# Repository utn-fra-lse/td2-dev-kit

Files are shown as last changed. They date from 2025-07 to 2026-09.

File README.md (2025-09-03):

# td2-dev-kit

El objetivo de este kit de desarrollo es proveer un hardware común para las plataformas de la cátedra de Técnicas Digitales II, siendo estas el ESP32 y la Raspberry Pi Pico 2.

## Pinouts de placas de desarrollo

Abajo están los pinouts de las placas de desarrollo que usamos en la cátedra

### ESP32 Devkit C1

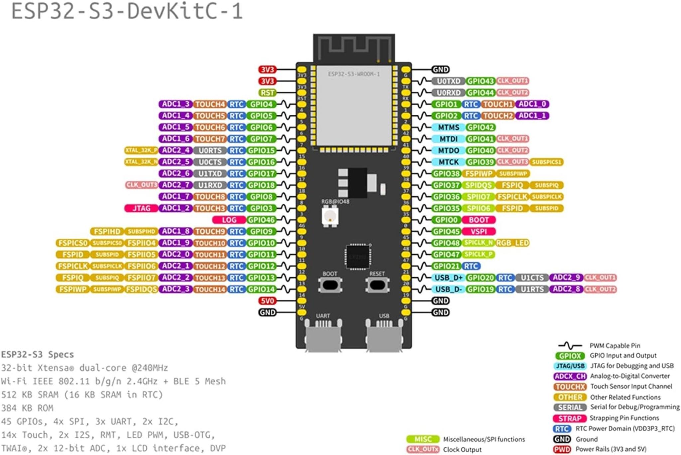
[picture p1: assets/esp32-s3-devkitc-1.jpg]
ESP32 S3 Devkit C1


### Raspberry Pi Pico 2W

Raspberry Pi Pico 2W

## Kit de desarrollo

Este va a ser nuestro kit de desarrollo para toda la cátedra.

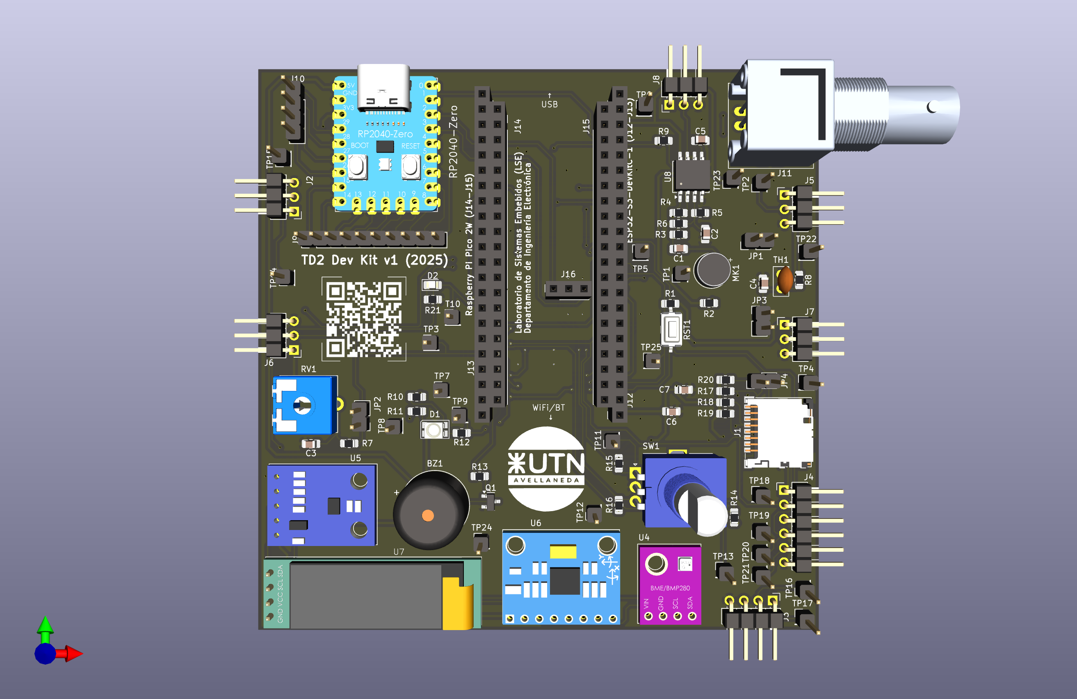
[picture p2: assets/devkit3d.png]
Dev kit


Tiene una variedad de periféricos para poder usar que a continuación vamos a mencionar brevemente.

### Entradas y salidas digitales

| GPIO RPico 2W | GPIO ESP32 | Dispositivo |
| --- | --- | --- |
| 2 | 9 | Output A de encoder rotativo |
| 3 | 10 | Output B de encoder rotativo |
| 12 | 37 | Botón de encoder rotativo |
| 11 | 8 | Buzzer pasivo |
| 10 | 38 | Ánodo LED individual |
| 15 | 5 | Cátodo LED rojo (RGB) |
| 13 | 6 | Cátodo LED verde (RGB) |
| 14 | 7 | Cátodo LED azul (RGB) | 

### Entradas analógicas

| GPIO RPico 2W | GPIO ESP32 | Dispositivo |
| --- | --- | --- |
| 26 | 1 | Micrófono |
| 27 | 2 | Potenciómetro |
| 28 | 4 | Termistor NTC |

En los tres casos, es posible anular las tres entradas analógicas a través de los jumpers `JP1`, `JP2` y `JP3` respectivamente. Al hacerlo, se puede conectar alguna entrada analógica externa con los conectores `J5`, `J6` y `J7`.

### Salida analógica

El kit provee una salida analógica a partir de PWM o DAC puro. Es posible medir la salida en `J8` o conectarla a un osciloscopio con el BNC provisto en `J11`.

| Microcontrolador | GPIO |
| --- | --- |
| RPico 2W | 22 |
| ESP32 | 21 |

En ambos casos, el GPIO disponible solo puede generar PWM pero se provee un seguidor de tensión con un filtro pasa bajos para convertir la salida de PWM en una salida analógica pura.

### Sensores y pantallas (I2C)

Todos los sensores y pantallas funcionan en el mismo bus de I2C como esclavos. Entre ellos tenemos:

* BME280 (Sensor de presión, humedad y temperatura).
* BH1750 (Sensor de luminosidad).
* MPU6050 (Acelerómetro y giróscopo).
* SSD1306 (Pantalla monocromática OLED de 128x32).

| Microcontrolador | I2C SDA | I2C SCL |
| --- | --- | --- |
| RPico 2W | 4 | 5 |
| ESP32 | 35 | 36 |

> En el caso del ESP32, es factible elegir cualquier bus. En la Raspberry Pi Pico 2W es el bus de I2C0.

Se provee un conector `J2` con los cuatro pines necesarios para conectar algún otro dispositivo I2C si fuese necesario.

### Tarjeta microSD

El kit provee las conexiones para hacer uso de almacenamiento en una microSD directamente por SPI.

| Microcontrolador | SPI MOSI | SPI MISO | SPI SCK | SPI CS |
| --- | --- | --- | --- | --- |
| RPico 2W | 19 | 16 | 18 | 17 |
| ESP32 | 48 | 45 | 47 | 46 |

> El bus de SPI para la Raspberry Pi Pico es el SPI0 mientras qye en el ESP32 es posible elegirlo.

Es posible anular la SD removiendo `JP4` y usando el conector `J3` para acceder a otro dispositivo SPI externo usando las mismas conexiones.

### UART

Si bien no se provee ningún dispositivo por UART en el propio kit, se deja la conexión disponible para usar a gusto con cualquier dispositivo externo.

| Microcontrolador | UART TX | UART RX |
| --- | --- | --- |
| RPico 2W | 8 | 9 |
| ESP32 | 43 | 44 |

> En la Raspberry Pi Pico 2W el UART usado es el UART1 mientras que en el ESP32 es el UART0.

### Debug Probe

En el caso del ESP32, este viene con un debugger en el propio kit. La Raspberry Pi Pico 2W no posee un debugger propio, por lo que se provee uno embebido en el kit de la cátedra en la forma de un RP2040. Este microcontrolador puede usarse para debuggear la Raspberry Pi Pico 2W o podría usarse como un microcontrolador adicional que agrega otros 14 GPIO disponibles en `J9` y `J10`.

### Test points

Se recopilaron las señales más relevantes en test points a lo largo de todo el kit.

| Test Point | Señal |
| --- | --- |
| TP1 | Salida del micrófono previo a amplificarse |
| TP2 | Canal analógico 0 |
| TP3 | Canal analógico 1 |
| TP4 | Canal analógico 2 |
| TP5 | PWM previo al filtro pasa bajos |
| TP6 | DAC puro |
| TP7 | RGB LED rojo |
| TP8 | RGB LED verde |
| TP9 | RGB LED azul |
| TP10 | LED amarillo |
| TP11 | Salida A del encoder |
| TP12 | Salida B del encoder |
| TP13 | Pulsador del encoder |
| TP14 | UART Tx |
| TP15 | UART Rx |
| TP16 | I2C SDA |
| TP17 | I2C SCL |
| TP18 | SPI MOSI |
| TP19 | SPI MISO |
| TP20 | SPI SCK |
| TP21 | SPI CS |
| TP22 | 3.3V |
| TP23 | 5V |
| TP24 | GND |
| TP25 | RESET |

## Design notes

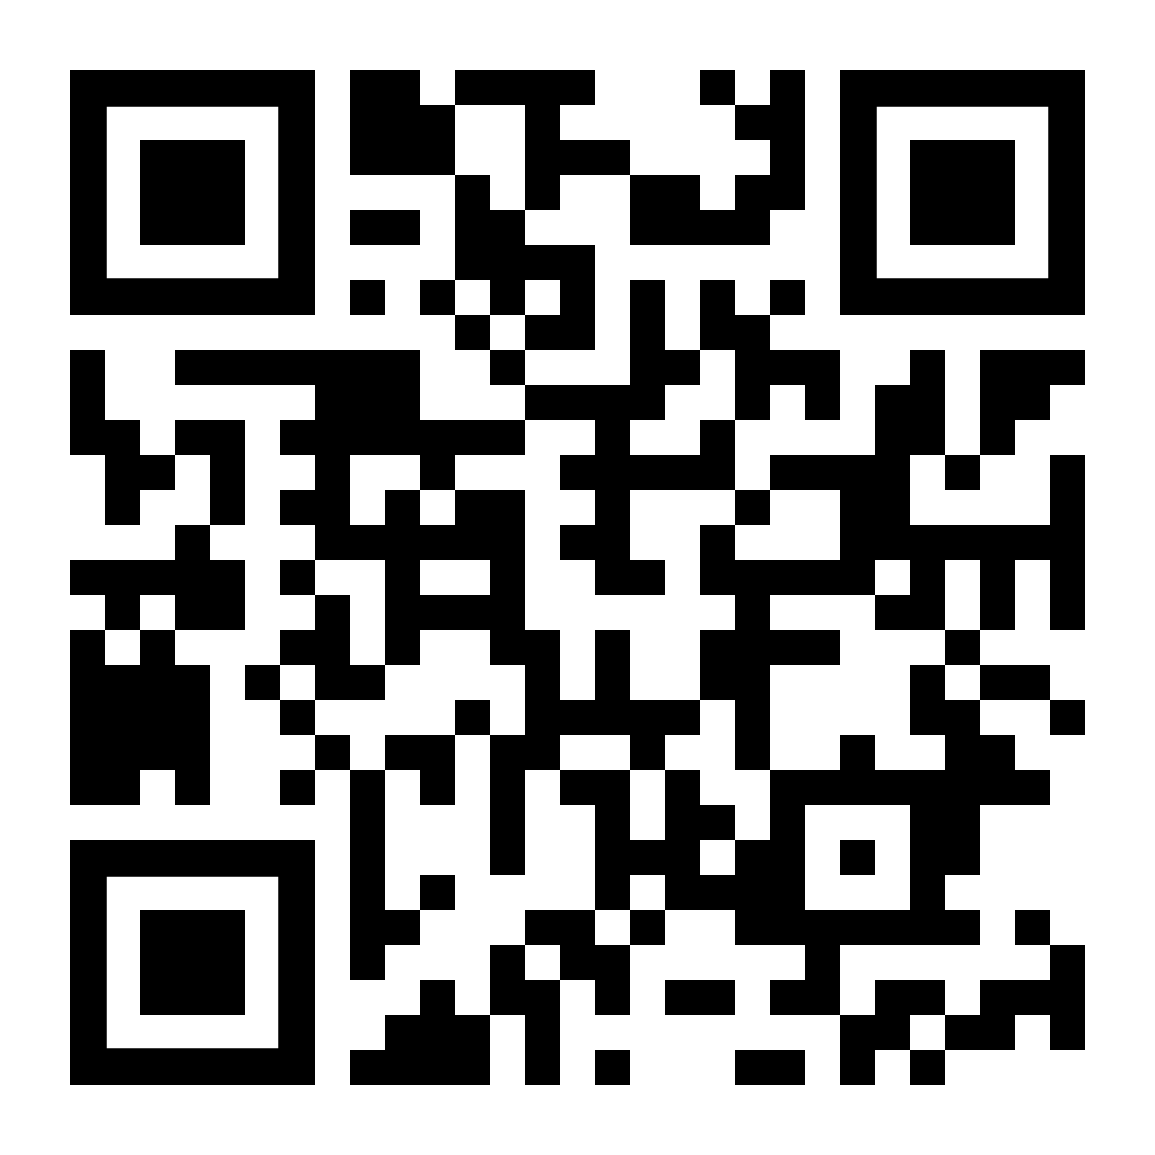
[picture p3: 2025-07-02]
qr.png

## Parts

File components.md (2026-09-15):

# Lista de Componentes

Esta es una lista de los componentes pertenecientes al kit.

[Excel con la lista](https://docs.google.com/spreadsheets/d/1ZjAvHHV7_DCwQpiGuCE5taRJxomZVwj_7CcSTuUQQDQ/edit?usp=sharing)

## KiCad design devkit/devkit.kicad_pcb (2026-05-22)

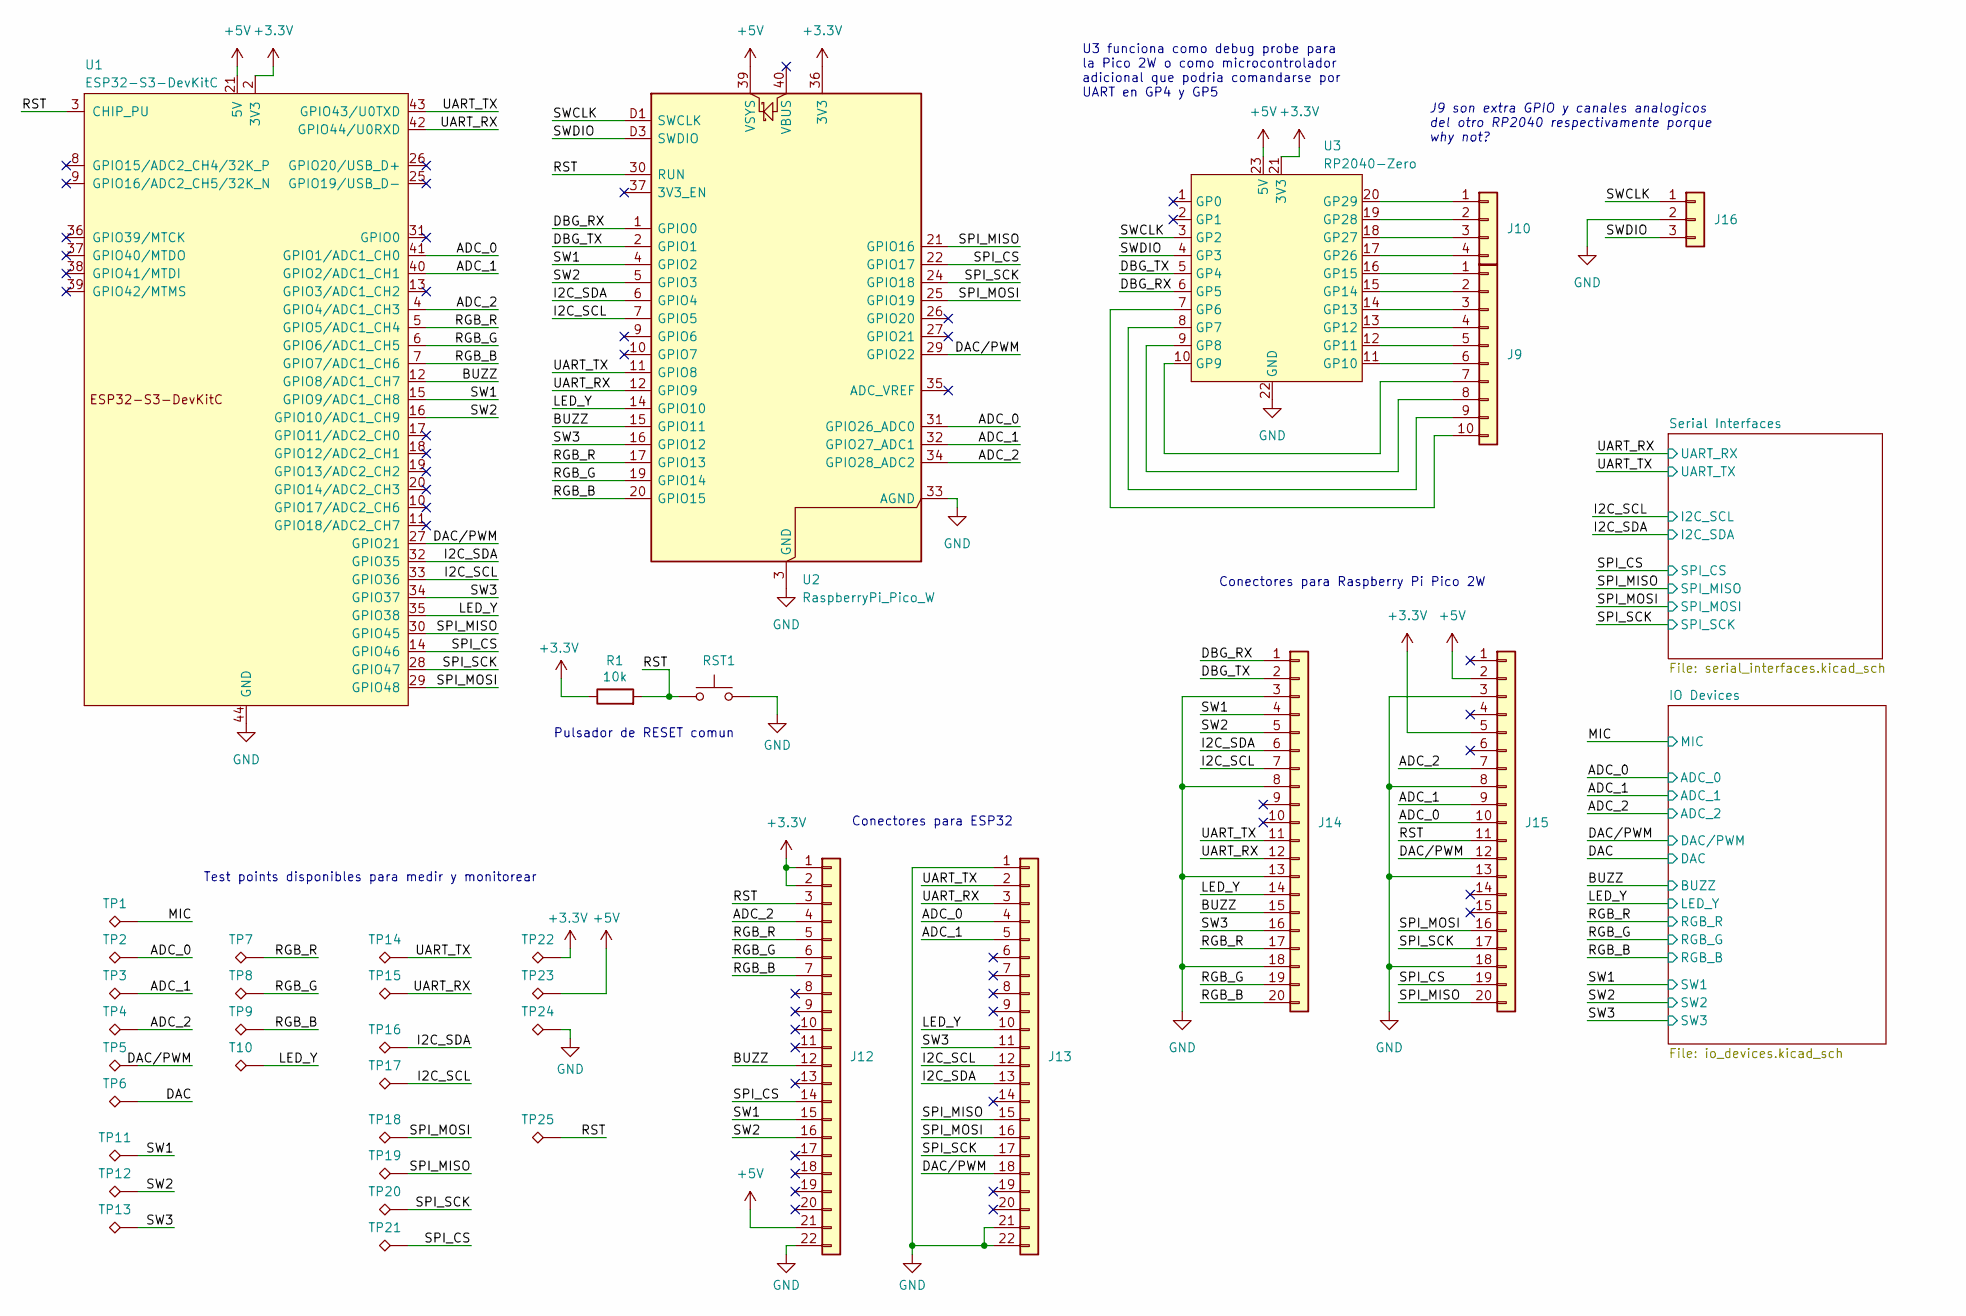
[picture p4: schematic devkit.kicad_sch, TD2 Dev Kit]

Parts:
J9: Conn_01x10; PinHeader_1x10_P2.54mm_Vertical
J10: Conn_01x04; PinHeader_1x04_P2.54mm_Vertical
J12, J13: Conn_01x22; PinSocket_1x22_P2.54mm_Vertical
J14, J15: Conn_01x20; PinSocket_1x20_P2.54mm_Vertical
J16: Conn_01x03; PinSocket_1x03_P2.54mm_Vertical
R1: 10k; R_0805_2012Metric_Pad1.20x1.40mm_HandSolder
RST1: RST; SW_Push_1P1T_NO_Vertical_Wuerth_434133025816
T10: TestPoint_Alt; PinHeader_1x01_P2.54mm_Vertical
TP1, TP2, TP3, TP4, TP5, TP6, TP7, TP8, TP9, TP11, TP12, TP13, TP14, TP15, TP16, TP17, TP18, TP19, TP20, TP21, TP22, TP23, TP24, TP25: TestPoint_Alt; PinHeader_1x01_P2.54mm_Vertical
U1: ESP32-S3-DevKitC
U2: RaspberryPi_Pico_W; RaspberryPi_Pico_Common_THT
U3: RP2040-Zero

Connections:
+3.3V: J12.1, J12.2, J15.5, R1.1, TP22.1, U1.1 (3V3), U1.2 (3V3), U2.36 (3V3), U3.21 (3V3); also elsewhere on the board
+5V: J12.21, J15.2, TP23.1, U1.21 (5V), U2.39 (VSYS), U3.23 (5V); also elsewhere on the board
/ADC_0: J13.4, J15.10, TP2.1, U1.41 (GPIO1/ADC1_CH0), U2.31 (GPIO26_ADC0); also elsewhere on the board
/ADC_1: J13.5, J15.9, TP3.1, U1.40 (GPIO2/ADC1_CH1), U2.32 (GPIO27_ADC1); also elsewhere on the board
/ADC_2: J12.4, J15.7, TP4.1, U1.4 (GPIO4/ADC1_CH3), U2.34 (GPIO28_ADC2); also elsewhere on the board
/BUZZ: J12.12, J14.15, U1.12 (GPIO8/ADC1_CH7), U2.15 (GPIO11); also elsewhere on the board
/DAC: TP6.1; also elsewhere on the board
/DAC/PWM: J13.18, J15.12, TP5.1, U1.27 (GPIO21), U2.29 (GPIO22); also elsewhere on the board
/DBG_RX: J14.1, U2.1 (GPIO0), U3.6 (GP5)
/DBG_TX: J14.2, U2.2 (GPIO1), U3.5 (GP4)
/I2C_SCL: J13.12, J14.7, TP17.1, U1.33 (GPIO36), U2.7 (GPIO5); also elsewhere on the board
/I2C_SDA: J13.13, J14.6, TP16.1, U1.32 (GPIO35), U2.6 (GPIO4); also elsewhere on the board
/LED_Y: J13.10, J14.14, T10.1, U1.35 (GPIO38), U2.14 (GPIO10); also elsewhere on the board
/MIC: TP1.1; also elsewhere on the board
/RGB_B: J12.7, J14.20, TP9.1, U1.7 (GPIO7/ADC1_CH6), U2.20 (GPIO15); also elsewhere on the board
/RGB_G: J12.6, J14.19, TP8.1, U1.6 (GPIO6/ADC1_CH5), U2.19 (GPIO14); also elsewhere on the board
/RGB_R: J12.5, J14.17, TP7.1, U1.5 (GPIO5/ADC1_CH4), U2.17 (GPIO13); also elsewhere on the board
/RST: J12.3, J15.11, R1.2, RST1.2, TP25.1, U1.3 (CHIP_PU), U2.30 (RUN); also elsewhere on the board
/SPI_CS: J12.14, J15.19, TP21.1, U1.14 (GPIO46), U2.22 (GPIO17); also elsewhere on the board
/SPI_MISO: J13.15, J15.20, TP19.1, U1.30 (GPIO45), U2.21 (GPIO16); also elsewhere on the board
/SPI_MOSI: J13.16, J15.16, TP18.1, U1.29 (GPIO48), U2.25 (GPIO19); also elsewhere on the board
/SPI_SCK: J13.17, J15.17, TP20.1, U1.28 (GPIO47), U2.24 (GPIO18); also elsewhere on the board
/SW1: J12.15, J14.4, TP11.1, U1.15 (GPIO9/ADC1_CH8), U2.4 (GPIO2); also elsewhere on the board
/SW2: J12.16, J14.5, TP12.1, U1.16 (GPIO10/ADC1_CH9), U2.5 (GPIO3); also elsewhere on the board
/SW3: J13.11, J14.16, TP13.1, U1.34 (GPIO37), U2.16 (GPIO12); also elsewhere on the board
/SWCLK: J16.1, U2.D1 (SWCLK), U3.3 (GP2)
/SWDIO: J16.3, U2.D3 (SWDIO), U3.4 (GP3)
/UART_RX: J13.3, J14.12, TP15.1, U1.42 (GPIO44/U0RXD), U2.12 (GPIO9); also elsewhere on the board
/UART_TX: J13.2, J14.11, TP14.1, U1.43 (GPIO43/U0TXD), U2.11 (GPIO8); also elsewhere on the board
GND: J12.22, J13.1, J13.21, J13.22, J14.3, J14.8, J14.13, J14.18, J15.3, J15.8, J15.13, J15.18, J16.2, RST1.1, TP24.1, U1.22 (GND), U1.23 (GND), U1.24 (GND), U1.44 (GND), U2.3 (GND), U2.8 (GND), U2.13 (GND), U2.18 (GND), U2.23 (GND), U2.28 (GND), U2.33 (AGND), U2.38 (GND), U2.D2 (GND), U3.22 (GND); also elsewhere on the board
unnamed: J9.1, U3.16 (GP15)
unnamed: J9.2, U3.15 (GP14)
unnamed: J9.3, U3.14 (GP13)
unnamed: J9.4, U3.13 (GP12)
unnamed: J9.5, U3.12 (GP11)
unnamed: J9.6, U3.11 (GP10)
unnamed: J9.7, U3.10 (GP9)
unnamed: J9.8, U3.9 (GP8)
unnamed: J9.9, U3.8 (GP7)
unnamed: J9.10, U3.7 (GP6)
unnamed: J10.1, U3.20 (GP29)
unnamed: J10.2, U3.19 (GP28)
unnamed: J10.3, U3.18 (GP27)
unnamed: J10.4, U3.17 (GP26)

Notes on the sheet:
J9 son extra GPIO y canales analogicos del otro RP2040 respectivamente porque why not?
Conectores para ESP32
Test points disponibles para medir y monitorear
Conectores para Raspberry Pi Pico 2W
U3 funciona como debug probe para la Pico 2W o como microcontrolador adicional que podria comandarse por UART en GP4 y GP5
Pulsador de RESET comun

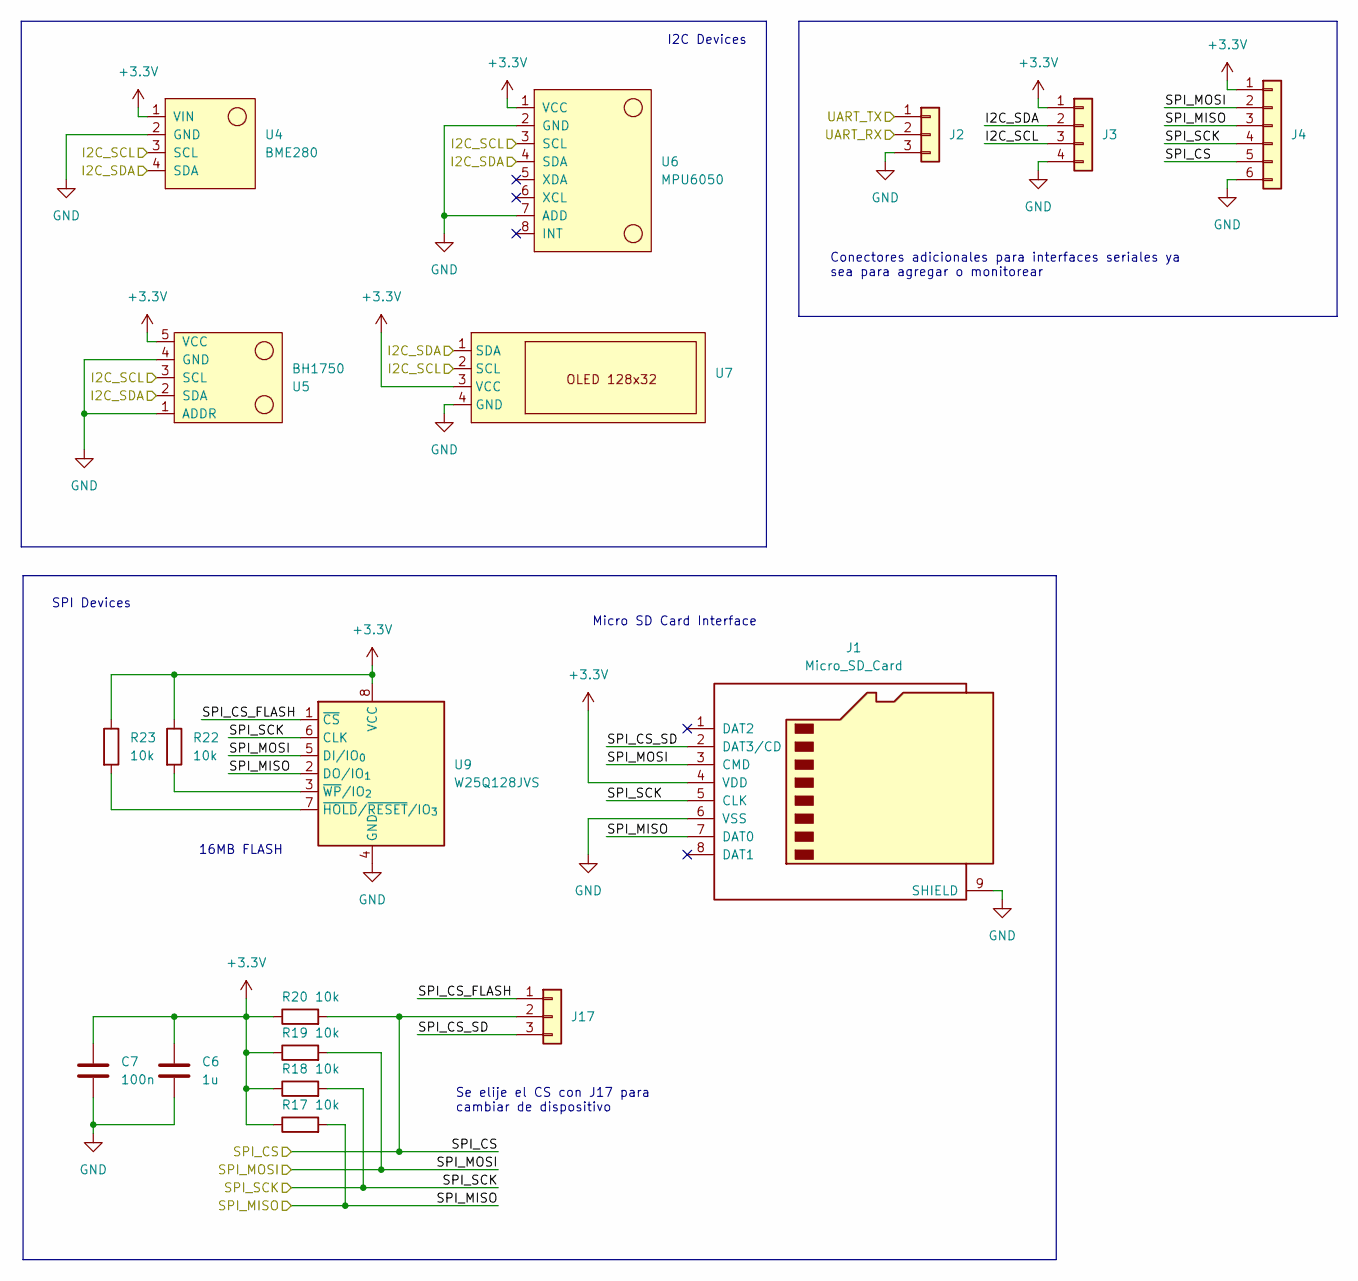
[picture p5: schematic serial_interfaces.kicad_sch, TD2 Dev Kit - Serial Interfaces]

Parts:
C6: 1u; C_0805_2012Metric_Pad1.18x1.45mm_HandSolder
C7: 100n; C_0805_2012Metric_Pad1.18x1.45mm_HandSolder
J1: Micro_SD_Card; microSD_HC_Molex_104031-0811
J2: Conn_01x03; PinHeader_1x03_P2.54mm_Horizontal
J3: Conn_01x04; PinHeader_1x04_P2.54mm_Horizontal
J4: Conn_01x06; PinHeader_1x06_P2.54mm_Horizontal
J17: Conn_01x03; PinHeader_1x03_P2.54mm_Vertical
R17, R18, R19, R20, R22, R23: 10k; R_0805_2012Metric_Pad1.20x1.40mm_HandSolder
U4: BME280; module_bme280_alt
U5: BH1750; module_bh1750
U6: MPU6050; module_mpu6050
U7: 128x32-OLED
U9: W25Q128JVS; SOIC-8_5.3x5.3mm_P1.27mm

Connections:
+3.3V: C6.1, C7.1, J1.4 (VDD), J3.1, J4.1, R17.1, R18.1, R19.1, R20.1, R22.1, R23.1, U4.1 (VIN), U5.5 (VCC), U6.1 (VCC), U7.3 (VCC), U9.8 (VCC); also elsewhere on the board
/I2C_SCL: J3.3, U4.3 (SCL), U5.3 (SCL), U6.3 (SCL), U7.2 (SCL); also elsewhere on the board
/I2C_SDA: J3.2, U4.4 (SDA), U5.2 (SDA), U6.4 (SDA), U7.1 (SDA); also elsewhere on the board
/SPI_CS: J4.5, J17.2, R20.2; also elsewhere on the board
/SPI_MISO: J1.7 (DAT0), J4.3, R17.2, U9.2 (DO/IO_{1}); also elsewhere on the board
/SPI_MOSI: J1.3 (CMD), J4.2, R19.2, U9.5 (DI/IO_{0}); also elsewhere on the board
/SPI_SCK: J1.5 (CLK), J4.4, R18.2, U9.6 (CLK); also elsewhere on the board
/Serial Interfaces/SPI_CS_FLASH: J17.1, U9.1 (~CS)
/Serial Interfaces/SPI_CS_SD: J1.2 (DAT3/CD), J17.3
/UART_RX: J2.2; also elsewhere on the board
/UART_TX: J2.1; also elsewhere on the board
GND: C6.2, C7.2, J1.6 (VSS), J1.9 (SHIELD), J1.10, J1.11, J2.3, J3.4, J4.6, U4.2 (GND), U5.1 (ADDR), U5.4 (GND), U6.2 (GND), U6.7 (ADD), U7.4 (GND), U9.4 (GND); also elsewhere on the board
unnamed: R23.2, U9.7 (~HOLD/~RESET/IO_{3})
unnamed: R22.2, U9.3 (~WP/IO_{2})

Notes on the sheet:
Conectores adicionales para interfaces seriales ya sea para agregar o monitorear
Se elije el CS con J17 para cambiar de dispositivo
I2C Devices
Micro SD Card Interface
16MB FLASH
SPI Devices

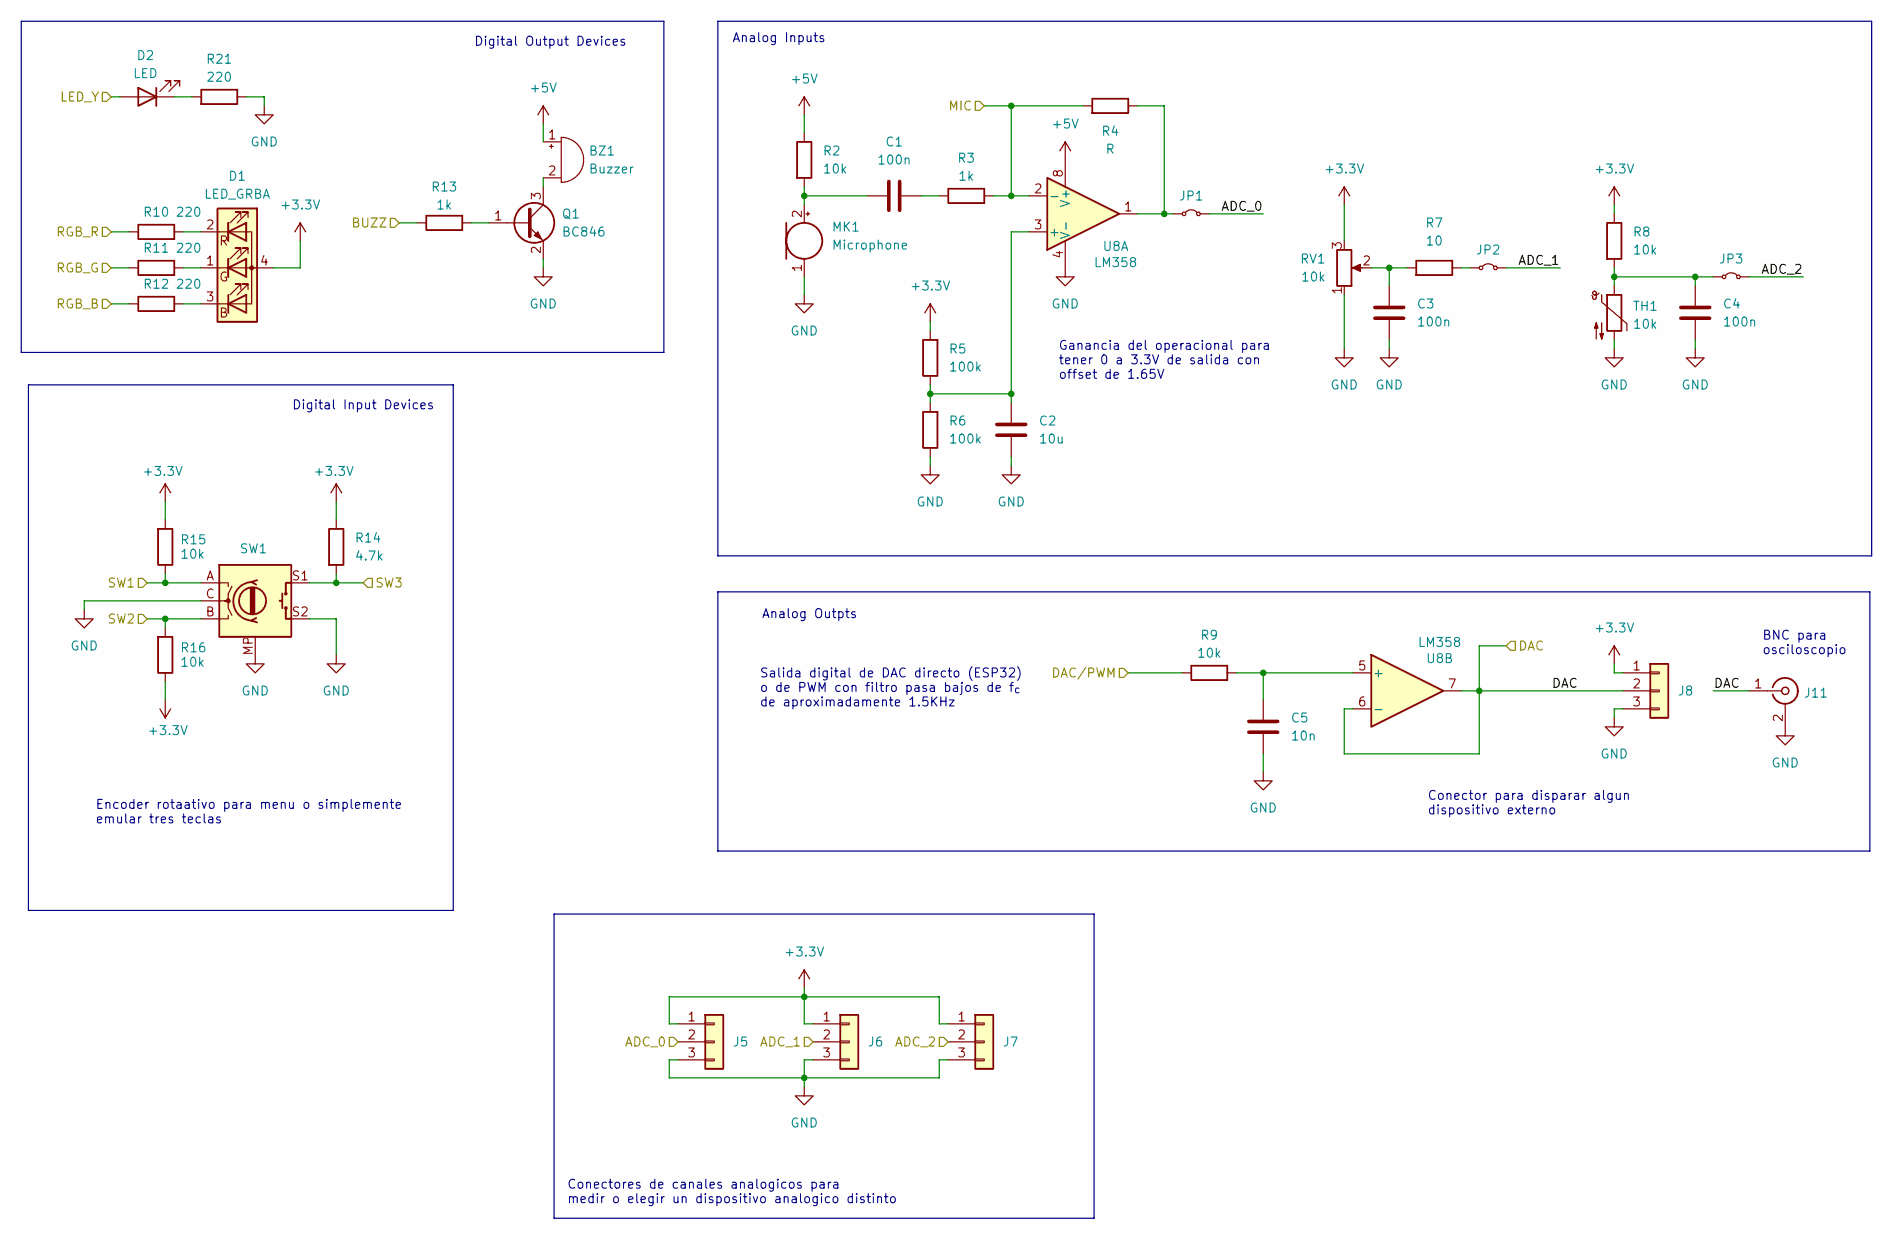
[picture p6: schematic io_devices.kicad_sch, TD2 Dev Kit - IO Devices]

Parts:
BZ1: Buzzer; Buzzer_12x9.5RM7.6
C1, C3, C4: 100n; C_0805_2012Metric_Pad1.18x1.45mm_HandSolder
C2: 10u; C_0805_2012Metric_Pad1.18x1.45mm_HandSolder
C5: 10n; C_0805_2012Metric_Pad1.18x1.45mm_HandSolder
D1: LED_GRBA; LED_Avago_PLCC4_3.2x2.8mm_CW
D2: LED; LED_0805_2012Metric_Pad1.15x1.40mm_HandSolder
J5, J6, J7, J8: Conn_01x03; PinHeader_1x03_P2.54mm_Horizontal
J11: Conn_Coaxial; BNC_Amphenol_B6252HB-NPP3G-50_Horizontal
JP1, JP2, JP3: Jumper_2_Small_Bridged; PinHeader_1x02_P2.54mm_Vertical
MK1: Microphone; POM-2244P-C3310-2-R
Q1: BC846; SOT-23
R2, R8, R9, R15, R16: 10k; R_0805_2012Metric_Pad1.20x1.40mm_HandSolder
R3, R13: 1k; R_0805_2012Metric_Pad1.20x1.40mm_HandSolder
R4: R; R_0805_2012Metric_Pad1.20x1.40mm_HandSolder
R5, R6: 100k; R_0805_2012Metric_Pad1.20x1.40mm_HandSolder
R7: 10; R_0805_2012Metric_Pad1.20x1.40mm_HandSolder
R10, R11, R12, R21: 220; R_0805_2012Metric_Pad1.20x1.40mm_HandSolder
R14: 4.7k; R_0805_2012Metric_Pad1.20x1.40mm_HandSolder
RV1: 10k; Potentiometer_ACP_CA9-V10_Vertical
SW1: RotaryEncoder_Switch_MP; RotaryEncoder_Alps_EC11E-Switch_Vertical_H20mm
TH1: 10k; C_Disc_D5.0mm_W2.5mm_P2.50mm
U8: LM358; SOIC-8_5.3x6.2mm_P1.27mm

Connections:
+3.3V: D1.4 (A), J5.1, J6.1, J7.1, J8.1, R5.2, R8.1, R14.1, R15.2, R16.1, RV1.3; also elsewhere on the board
+5V: BZ1.1 (+), R2.1, U8.8 (V+); also elsewhere on the board
/ADC_0: J5.2, JP1.2 (B); also elsewhere on the board
/ADC_1: J6.2, JP2.2 (B); also elsewhere on the board
/ADC_2: J7.2, JP3.2 (B); also elsewhere on the board
/BUZZ: R13.1; also elsewhere on the board
/DAC: J8.2, J11.1 (In), U8.6 (-), U8.7; also elsewhere on the board
/DAC/PWM: R9.1; also elsewhere on the board
/LED_Y: D2.2 (A); also elsewhere on the board
/MIC: R3.2, R4.2, U8.2 (-); also elsewhere on the board
/RGB_B: R12.1; also elsewhere on the board
/RGB_G: R11.1; also elsewhere on the board
/RGB_R: R10.1; also elsewhere on the board
/SW1: R15.1, SW1.A; also elsewhere on the board
/SW2: R16.2, SW1.B; also elsewhere on the board
/SW3: R14.2, SW1.S1; also elsewhere on the board
GND: C2.2, C3.2, C4.2, C5.2, J5.3, J6.3, J7.3, J8.3, J11.2 (Ext), MK1.1 (-), Q1.2 (E), R6.1, R21.1, RV1.1, SW1.C, SW1.MP, SW1.S2, TH1.2, U8.4 (V-); also elsewhere on the board
unnamed: BZ1.2 (-), Q1.3 (C)
unnamed: C1.2, R3.1
unnamed: C3.1, R7.2, RV1.2
unnamed: D1.3 (BK), R12.2
unnamed: D1.1 (GK), R11.2
unnamed: D1.2 (RK), R10.2
unnamed: D2.1 (K), R21.2
unnamed: JP1.1 (A), R4.1, U8.1
unnamed: JP2.1 (A), R7.1
unnamed: C4.1, JP3.1 (A), R8.2, TH1.1
unnamed: C1.1, MK1.2 (+), R2.2
unnamed: Q1.1 (B), R13.2
unnamed: C2.1, R5.1, R6.2, U8.3 (+)
unnamed: C5.1, R9.2, U8.5 (+)

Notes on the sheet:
BNC para osciloscopio
Analog Inputs
Digital Input Devices
Encoder rotaativo para menu o simplemente emular tres teclas
Analog Outpts
Digital Output Devices
Salida digital de DAC directo (ESP32) o de PWM con filtro pasa bajos de f_{c} de aproximadamente 1.5KHz
Ganancia del operacional para tener 0 a 3.3V de salida con offset de 1.65V
Conectores de canales analogicos para medir o elegir un dispositivo analogico distinto
Conector para disparar algun dispositivo externo

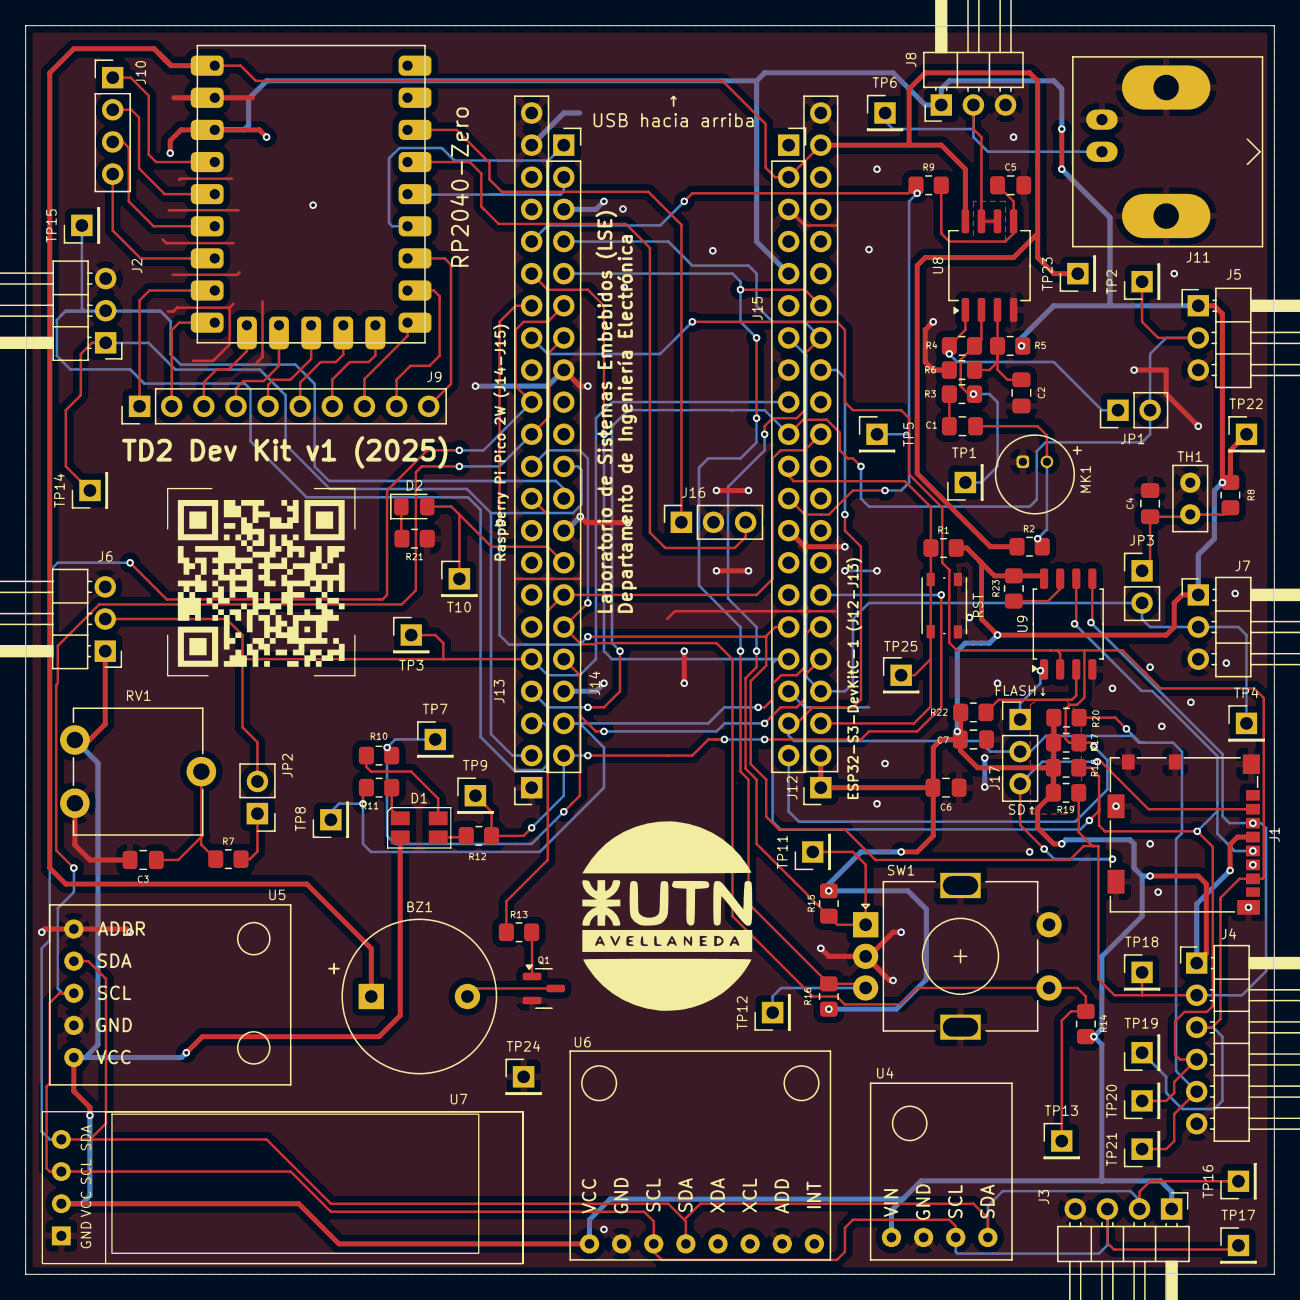
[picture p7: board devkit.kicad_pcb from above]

Board: 2 copper layers, 98.7 x 98.7 mm, 91 parts (0 on the bottom side), 62 nets.

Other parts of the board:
RST: RST; SW_Push_1P1T_NO_Vertical_Wuerth_434133025816

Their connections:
/RST: RST.2; also elsewhere on the board
GND: RST.1; also elsewhere on the board

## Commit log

2025-07-01 feat: primer version de esquematico y pcb
    [devkit.kicad_pcb, devkit.kicad_sch, io_devices.kicad_sch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]
2025-07-02 chore: logos y qr para pcb
2025-07-02 chore: actualizo algunas huellas e info en pcb
    [devkit.kicad_pcb, devkit.kicad_sch, io_devices.kicad_sch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]
2025-07-16 feat: adicion de memoria flash
    [devkit.kicad_pcb, serial_interfaces.kicad_sch]
2025-09-03 fix: corrección re referencias de pines de LEDs de la Raspberry Pi Pico
2026-05-22 fix: fix sd connector orientation
    [devkit.kicad_pcb]
2026-09-15 feat: crear lista de componentes
